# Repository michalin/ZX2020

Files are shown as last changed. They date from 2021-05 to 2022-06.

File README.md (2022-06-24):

# ZX 2020

Yet another homebuilt Z80 Computer, but this one works without any FPGAs or Microcontrollers, but components that were available at the time when the Z80 processor was state of the art. With only five ICs it can run historic programs like Multiplan, Wordstar and MBasic, as well as some games. It now supports PATA drives. This is a reminiscense to the Sinclair ZX81 computer. 

## To build the ZX 2020, do the following
- Wire the parts on a breadboard or perfboard like shown in the schematic
- Copy the CPM directory tree to any location on your PC, e.g. your user directory 
- Load the Arduino Sketch into an Arduino Mega
- Connect the TxDB and RxDB pins of the DART with a Serial-USB converter or Pin 0 and 1 of your Arduino Mega
- Start a serial terminal emulation, for example "Putty", set 125000 Baud, 8 Bit, 1 Stopbit, no parity
- Compile and run the tool `cpmloader.exe`. Then click on "Load CP/M" and select the file `bootldr.com`
- When a welcome message and the CP/M prompt "A>" appears on your terminal emulation, the ZX2020 is ready to use. If you have a PATA compatible hard drive connected, you need to format it with the "mkdsk" tool before you can use it. Note that all data on the disk will be lost. 

## Notes on TMS9918 Video Display Processor
CP/M is pre-built for supporting a PS/2 compatible keyboard and a TV or monitor. When using without a TMS99x8 (Serial connection only), you can change the following parameters in gencpm.dat and rebuild.
- MEMTOP   = FF  
- PAGWID   = 50  (80 columns)

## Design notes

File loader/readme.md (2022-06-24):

This is the Arduino Sketch that writes the CP/M bootloader file `(bootldr.com)` directly into RAM and starts CP/M when finished. After that it serves as serial-USB converter for the serial disk emulation.
### Todo
Open the sketch with Arduino-IDE or any other IDE with AVM support and select *`Tools->Board->"Arduino Mega or Mega 2560`*.

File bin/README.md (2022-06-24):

Executables used to build CP/M sources under Windows.
Taken from ZXCC Software CP/M emulator for Windows - based on John Elliott's zxcc
https://github.com/Tbxxx/zxcc-windows

Zmac relocatable Z80 Macro assembler: http://48k.ca/zmac.html

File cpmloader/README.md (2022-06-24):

This is the QT App that lets you upload the CP/M bootloader (bootldr.com) to your Z80 computer via the Arduino Mega. It also serves as serial "Fileserver". I recommend to use Qt Creator 7.0.1 along with QT 6.3.0/MinGW 11.2.0 64-bit and Gnu make utility for Windows to build the executable. I developed and tested all under Windows 10, but it might also work on other platforms that are supported by QT. I have never tested this, so I cannot tell whether it works. It does not matter where the bootloader executable is located, but it will ask for the location of the CP/M root directory when you click the "load CP/M" button for the first time. The Root directory must contain the bootldr.com file and the folder "driveA" that contains the CP/M programs in up to 16 user folders.
Note that the maximal file size is 128 Kilobyte, which is enough for most cases.

https://www.qt.io

http://gnuwin32.sourceforge.net/packages/make.htm

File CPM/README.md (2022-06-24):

This folder contains the system files, sources and some CP/M user programs in the directory *driveA*. You only need to compile the source files (*.asm), if you want to make changes to the kernel. 

**Compiling CP/M and auxiliary programs (if necessary)**
Requirements: 

 - Windows command prompt or PowerShell
 - GNU make utility for Windows: gnuwin32.sourceforge.net/packages/make.htm

todo:
- Add GNU make utiliy executable (make.exe) to your Path.
- Open command shell, cd into this directory and type "make"

When using without TMS99x8 (Serial connection only), you can change the following parameters in gencpm.dat and rebuild.
- MEMTOP   = FF  
- PAGWID   = 50  (80 columns)

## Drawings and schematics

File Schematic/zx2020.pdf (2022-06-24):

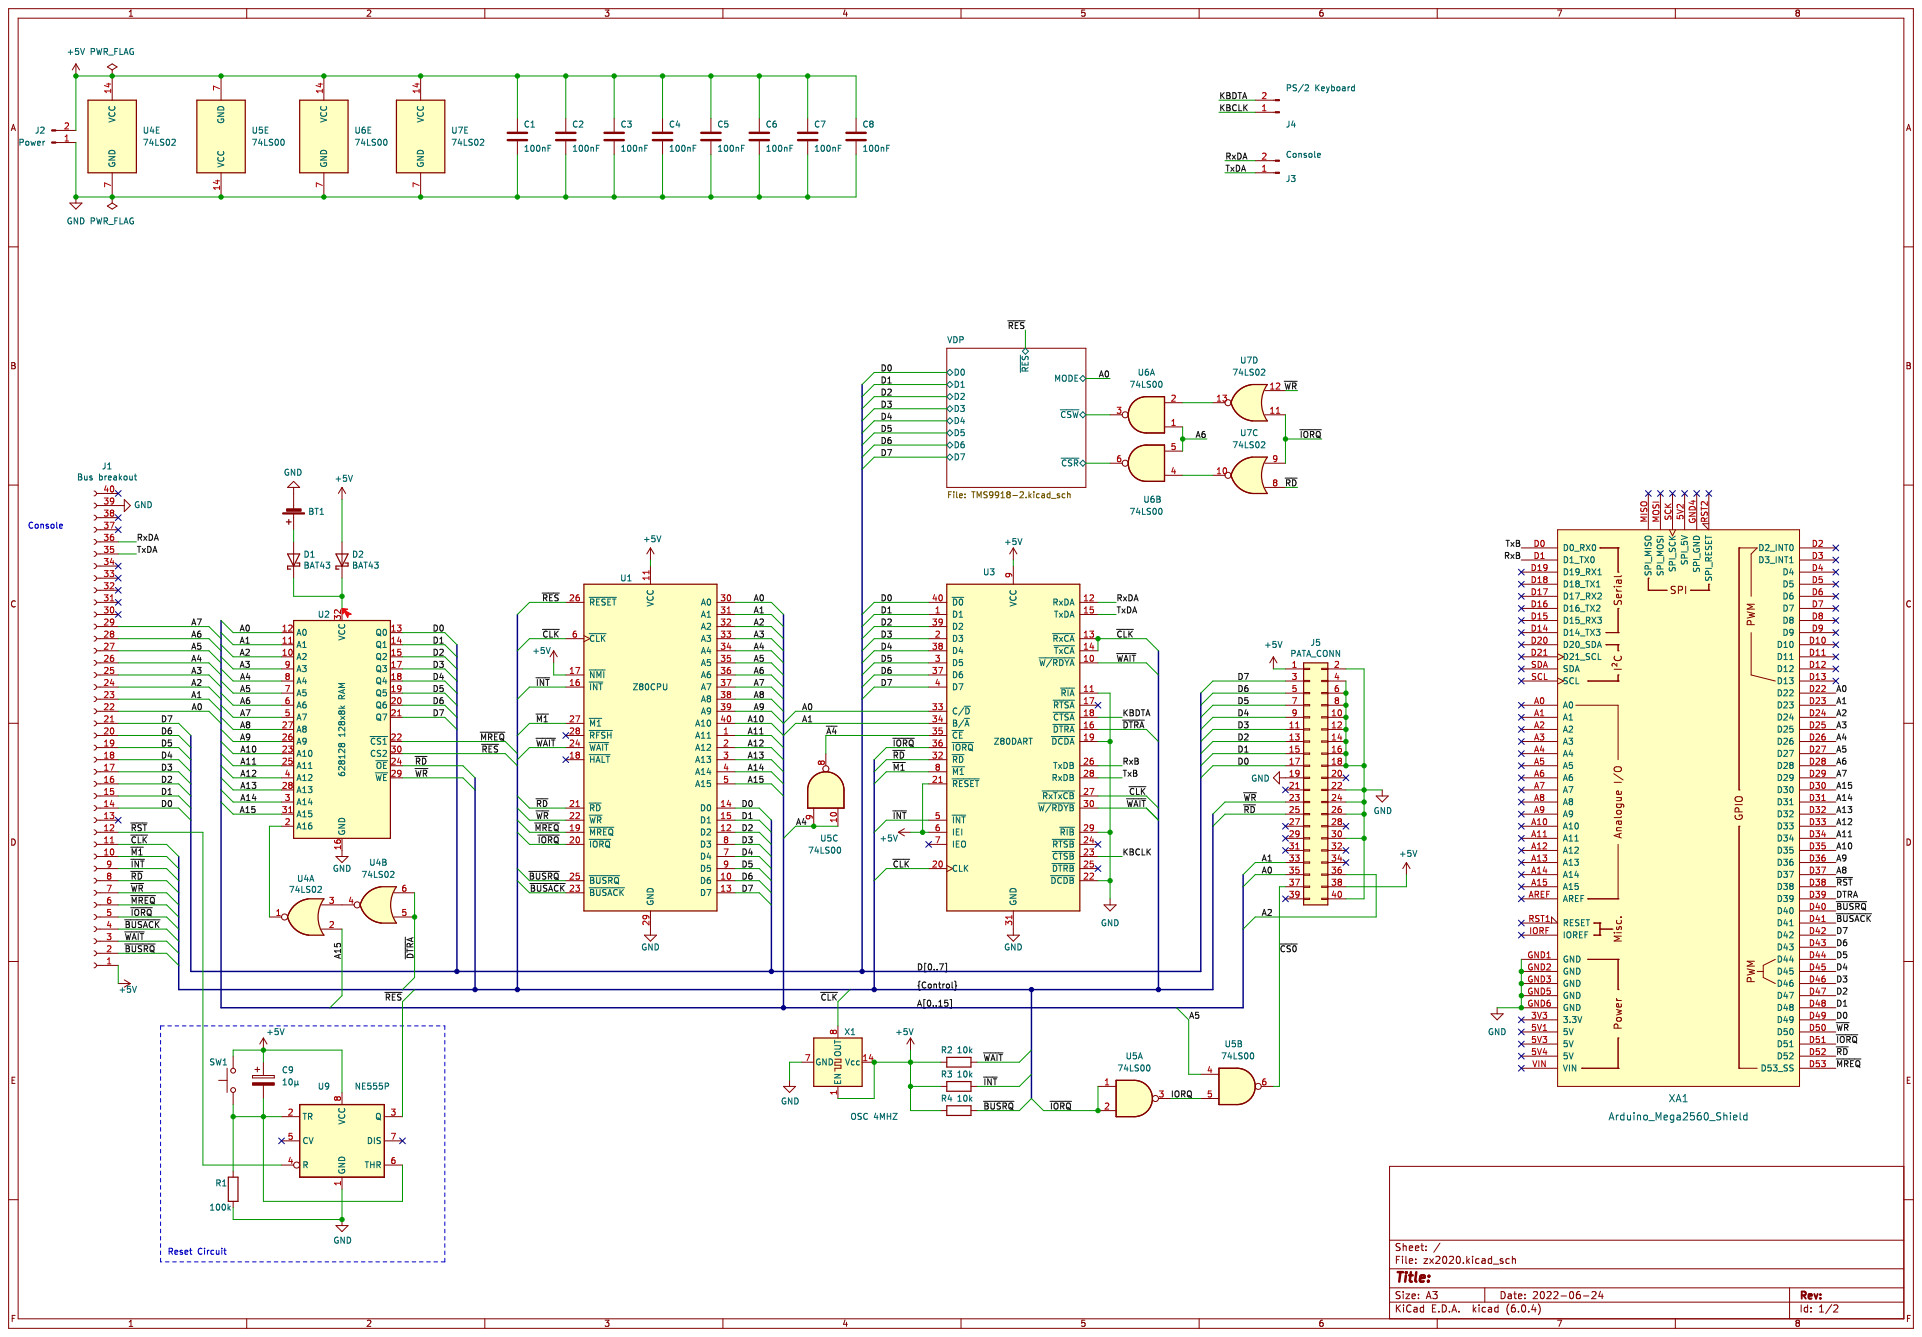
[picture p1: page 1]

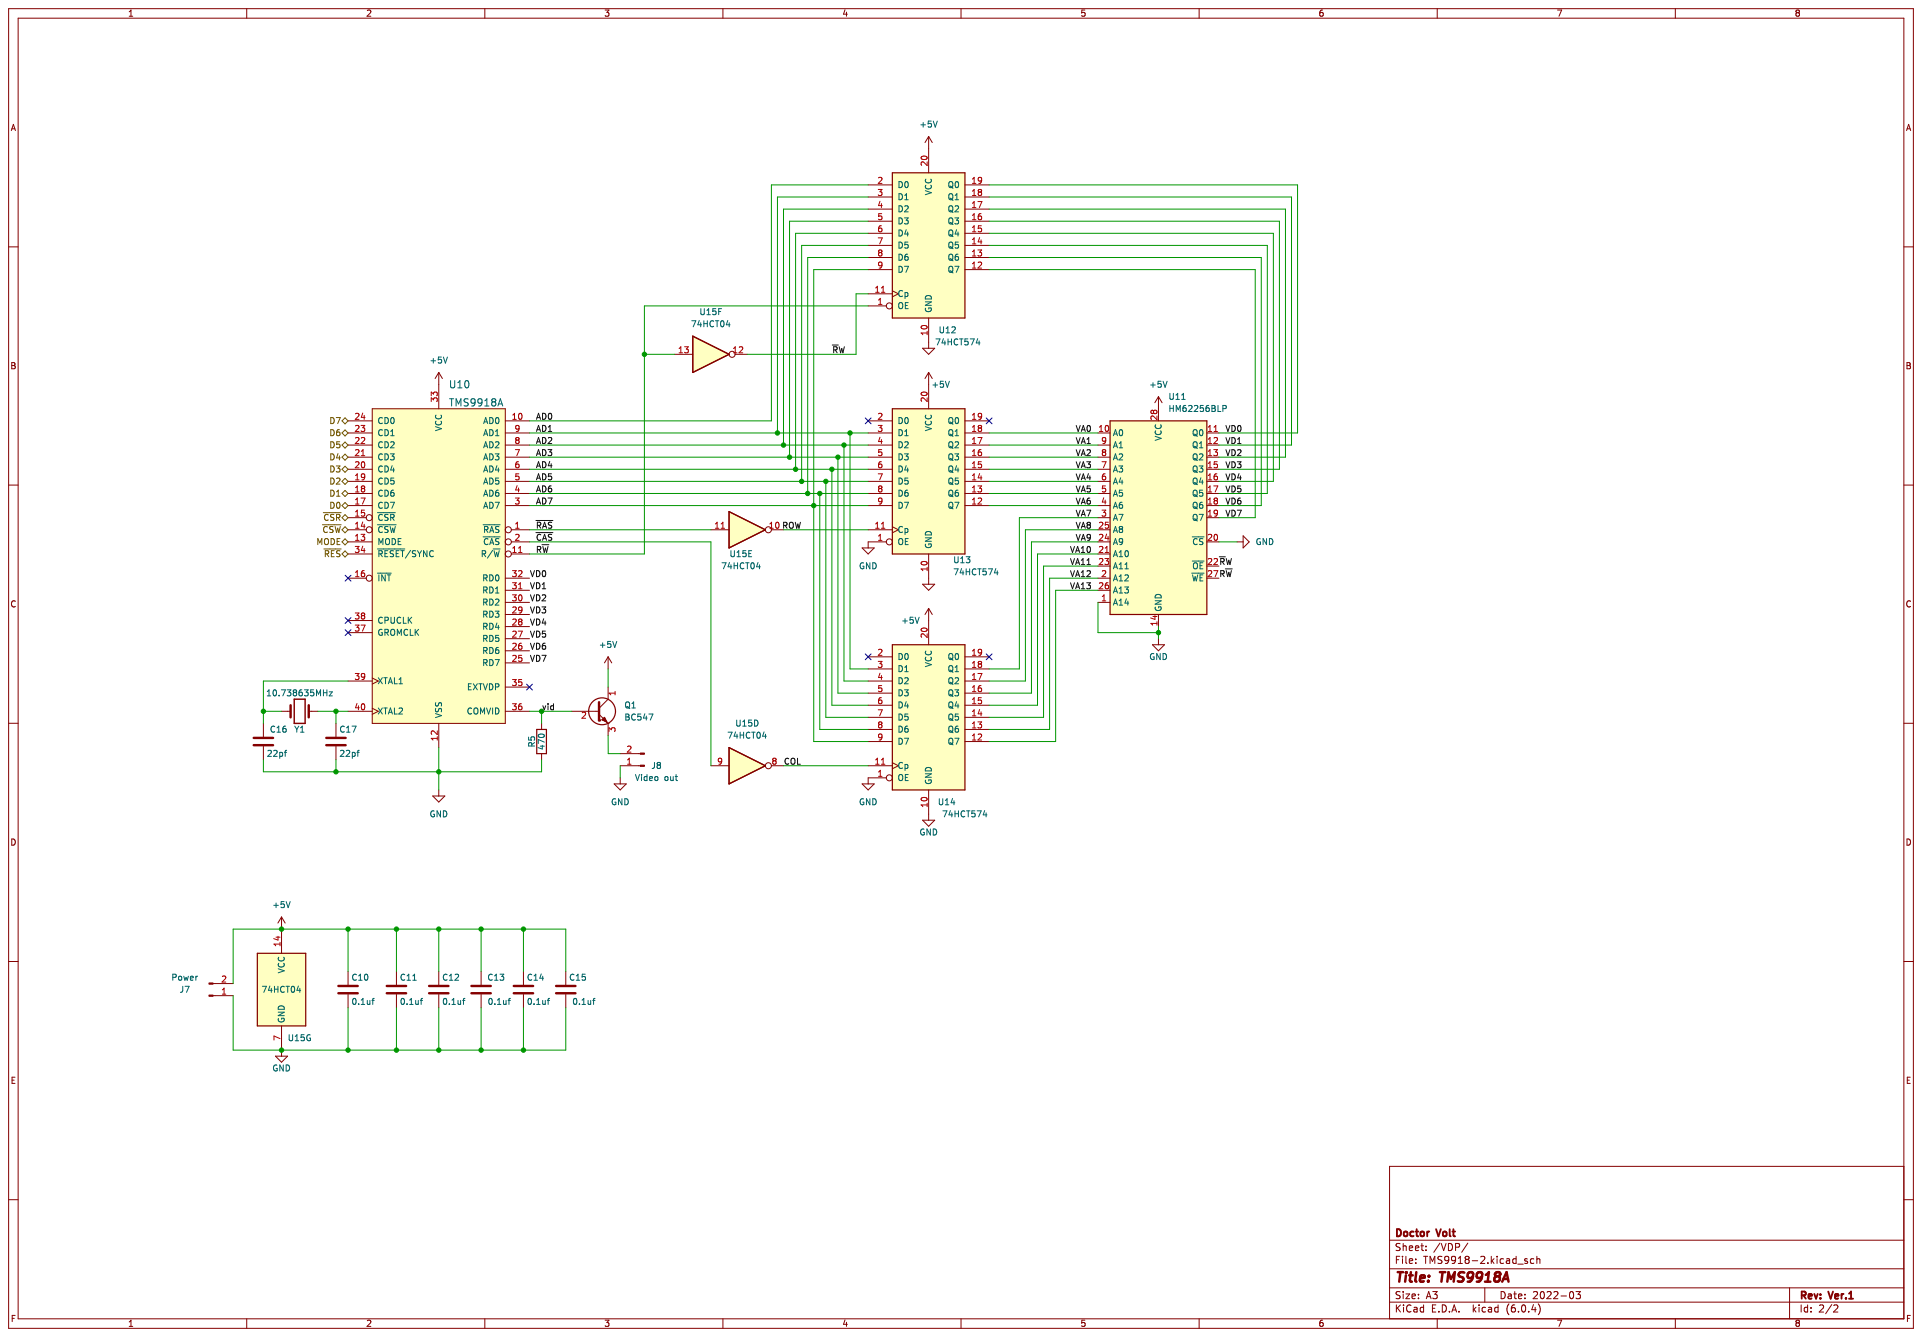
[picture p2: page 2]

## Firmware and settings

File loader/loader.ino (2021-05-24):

/* Copyright (C) 2020  Doctor Volt

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
 You should have received a copy of the GNU General Public License
 along with this program.  If not, see <https://www.gnu.org/licenses/>.
*/
//#include "serdisk.h"
#include "Z80.h"
#include "sram.h"
#include "debug.h"

#define CHUNKLEN 32

bool wait4chunk = false; //Synchronization

//Parameter structure for the @ldcpm command
struct Ldaddr
{
  uint16_t base; //Memory address where the image starts
  uint16_t size; //Size of the image
  uint16_t reserved; //
} ldaddr;

void on_dtra();

void setup()
{
  bus_idle();
  Serial.begin(125000);
  //Check if there is a response on busrequest if not: ZX2020 not connected
  bool connected = true;
  if(!BUSRQ(ACTIVE))
  {
    connected = false;
  }
  if(!BUSRQ(PASSIVE))
  {
    connected = false;
  }
  if(!connected)
  {
    println("Not connected to ZX 2020 bus");
    Serial.end(); 
    return;
  }
  println("ZX 2020 bus connected");
  Serial.write("<$>ready</$>");

  RESET();
  BUSRQ(ACTIVE);
  //attachInterrupt(digitalPinToInterrupt(39), on_dtra, FALLING);
}
void serialEvent()
{
  static int bytestoload = 0;
  char chunk[CHUNKLEN];
  Serial.readBytes(chunk, CHUNKLEN); //Read chunk
  if (bytestoload == 0)              //Is it a command from PC? (@...@)
  {
    //Handle commands
    String command = String(chunk); // Serial.readString();
    //println(command.c_str());

    if (command.startsWith("@ldcpm")) //Start start addr and size Kernel
    {
      //BUSRQ(ACTIVE);
      for (uint16_t i = 0x0000; i < 0xffff; i++) //Delete memory
        sramWrite(i, 0);

      //Get start address and total number of bytes expected
      memcpy(&ldaddr, (chunk + 6), sizeof(ldaddr));
      println("Loading image file to Ram. Base: 0x%04X, size: 0x%04x", ldaddr.base, ldaddr.size);
      bytestoload = ldaddr.size;
      
      Serial.write("<$>rqcpm</$>"); //Signal for loader to send Kernel
      return;
    }
    else if (command.startsWith("@test")) //Test functions
    {
      BUSRQ(ACTIVE);
      println("Test");
      return;
    }
  }
  else if (bytestoload > 0) //Is there data to load into SRAM?
  {
    static uint16_t addr = ldaddr.base; //start addr = BDOS address
    for (int i = 0; i < CHUNKLEN; i++)
    {
      sramWrite(addr++, chunk[i]);
      bytestoload--;
    }
    if (bytestoload == 0)
    {
      println("Memory image loaded");
      Serial.write("<$>started</$>"); //Report to loader Z80 started

      if (!BUSRQ(PASSIVE))
      {
        println("Error: busrq failed");
      }
      //serdisk = true;
      RESET();
      println("Z80 restarted");
      Serial.end(); //Now the ZX2020 can use the interface
      bus_idle();
    }
  }
}

void bus_idle(){
  DDRA = 0; PORTA = 0;
  DDRB = 0; PORTB = 0;
  DDRC = 0; PORTC = 0;
  DDRD = 0; PORTD = 0;
  ;DDRE = 0; ;PORTE = 0;
  DDRG = 0; PORTG = 0;
  DDRL = 0; PORTL = 0;
}

void on_dtra()
{
  println("dtra");
}

void loop()
{

}

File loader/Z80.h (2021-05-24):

/* Copyright (C) 2020  Doctor Volt

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
 You should have received a copy of the GNU General Public License
 along with this program.  If not, see <https://www.gnu.org/licenses/>.
*/

#ifndef Z80_H
#define Z80_H

#include "Arduino.h"
//Port B
#define MREQ_PIN PB0 //(Arduino Pin 53) Z80 Pin 19
#define RD_PIN PB1   //(Arduino Pin 52) Z80 Pin 21
#define IORQ_PIN PB2 //Arduino Pin 51) Z80 Pin 20
#define WR_PIN PB3   //(Arduino Pin 50) Z80 Pin 22
#define CLK_PIN PB4  //(Arduino Pin 10) Z80 Pin 6
//Port G
#define BUSACK_PIN PG0 //(Arduino Pin 41) Z80 Pin 23
#define BUSRQ_PIN PG1  //(Artduino Pin 40) Z80 Pin 25
//#define RESERVED PG2   
//Port D
#define RST_PIN PD7 //(Arduino Pin 38) Z80 PIN 26
//Port E
#define TX0_PIN PE0 //(Arduino Pin0 / RX0)
#define TX1_PIN PE1 //(Arduino Pin1 / TX1)
//Address bus
#define ADDR_LO PINA //A0..A7
#define ADDR_HI PINC //A8..A9
#define ADDR ((ADDR_HI << 8) + ADDR_LO)

#define ACTIVE 1  //0V
#define PASSIVE 0 //5V, pulled up by 10k resistor

inline void RD(uint8_t b)
{
  (b == ACTIVE) ? bitClear(PORTB, RD_PIN) : bitSet(PORTB, RD_PIN);
}
inline void WR(uint8_t b)
{
  (b == ACTIVE) ? bitClear(PORTB, WR_PIN) : bitSet(PORTB, WR_PIN);
}

inline void MREQ(uint8_t b)
{
  (b == ACTIVE) ? bitClear(PORTB, MREQ_PIN) : bitSet(PORTB, MREQ_PIN);
}

inline void IORQ(uint8_t b)
{
  (b == ACTIVE) ? bitClear(PORTB, IORQ_PIN) : bitSet(PORTB, IORQ_PIN);
}

/*inline void WAIT(bool b)
{
  //bitSet(DDRB, WAIT_PIN); //Pulled up by 10k resistor
  b == ACT_LO ? bitSet(DDRB, WAIT_PIN) : bitClear(DDRB, WAIT_PIN);
}
inline bool RD()
{
  bitClear(DDRB, RD_PIN);
  return !bitRead(PINB, RD_PIN);
}
inline bool WR()
{
  bitClear(DDRB, WR_PIN);
  return !bitRead(PINB, WR_PIN);
}
inline bool MREQ()
{
  bitClear(DDRB, MREQ_PIN);
  return !bitRead(PINB, MREQ_PIN);
}
inline bool IORQ()
{
  bitClear(DDRB, IORQ_PIN);
  return !bitRead(PINB, IORQ_PIN);
}
inline bool BUSACK()
{
  bitClear(DDRG, BUSACK_PIN);
  return !bitRead(PING, BUSACK_PIN);
}
*/

inline bool BUSRQ(bool b)
{
  if (b) //Allocate bus
  {
    DDRA = 0xFF;
    DDRB |= (1 << RD_PIN) + (1 << WR_PIN) + (1 << MREQ_PIN) + (1 << IORQ_PIN);
    PORTB |= (1 << RD_PIN) + (1 << WR_PIN) + (1 << MREQ_PIN) + (1 << IORQ_PIN);
    DDRC = 0xFF;
    DDRL = 0xFF;
    bitSet(DDRG, BUSRQ_PIN);
  }
  else //Free bus
  {
    DDRA = 0;
    DDRB &= ~((1 << RD_PIN) + (1 << WR_PIN) + (1 << MREQ_PIN) + (1 << IORQ_PIN));
    DDRC = 0;
    DDRL = 0;
    bitClear(DDRG, BUSRQ_PIN);
  }

  uint8_t i = 0;
  while (bitRead(PING, BUSACK_PIN) == b)
  {
    if (i++ == 10)
    { //Allow 10 retries, then return error
      return 0;
    }
    delay(1);
  }
  return 1;
}

inline void RESET(bool b)
{
  b == ACTIVE ? bitSet(DDRD, RST_PIN) : bitClear(DDRD, RST_PIN);
}
inline void RESET()
{
  RESET(ACTIVE);
  delay(100);
  RESET(PASSIVE);
}

void sramWrite(uint16_t, uint8_t);

#endif

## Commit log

2020-07-16 CPM.ZIP unpacked
    [support.cfg]
2021-05-24 Version 2.0
    Boots from hard drive
    [support.cfg, zx2020.sch]
2022-06-24 Update BOOT.ASM
    Re-written in Z80 assembly for support of PS/2 and TMS 99x8
2022-06-24 Update
    Re-written in Z80 assembly for TMS99x8 support
2022-06-24 Update CHARIO.ASM
    Interrupt routines for PS/2 keyboard interrupts, driver for TMS99x8
2022-06-24 Create isrtbl.asm
    Interrupt handling
2022-06-24 Update Makefile
    - rmac.exe and drilink.exe running on Windows without ZXCC.
    - ZMAC to assemble sources files written in Z80 assembly
2022-06-24 Create vdp.asm
    Driver for TMS99x8 Video Display Processor

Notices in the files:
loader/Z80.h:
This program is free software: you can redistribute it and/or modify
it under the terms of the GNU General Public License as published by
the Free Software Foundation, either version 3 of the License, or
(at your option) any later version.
